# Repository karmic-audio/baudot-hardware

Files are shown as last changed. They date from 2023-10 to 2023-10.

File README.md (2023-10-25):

# baudot hardware

Based on the Monome Teletype.

Schematic/PCB diagram converted from Eagle to KiCAD.

Firmware: https://github.com/karmic-audio/baudot-software

## License

CC-BY-SA 3.0. Do not use the name "monome" or "teletype" in derivative works.

Created by brian crabtree (bcrabtree@monome.org)
Modified by Serge Bazanski (q3k@q3k.org) for Karmic Audio.

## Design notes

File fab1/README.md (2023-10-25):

Production files used for the first fabrication run of the Baudot.

Started at: March 2023

PCB Manufacturer: Aisler

PCB assembly: Karmic

Module asembly: Karmic

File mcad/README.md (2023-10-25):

Mechanicals for Baudot
===

screen-frame.FCStd
---

Screen frame used between OLED module and screen protector / front panel.

Designed with FreeCAD.

button.FCStd
---

NMI button for placement over microswitch.

Designed with FreeCAD.

screen-protector.slvs
---

Screen protector cutout from PETG.

Designed with Solvespace, because DXF/SVG export from FreeCAD confuses me.

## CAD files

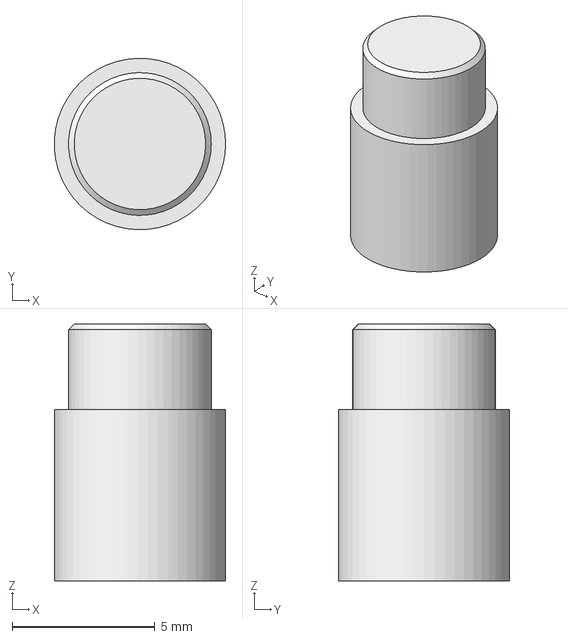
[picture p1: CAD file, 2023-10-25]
mcad/button.FCStd
5.99 x 6.00 x 9.00 mm

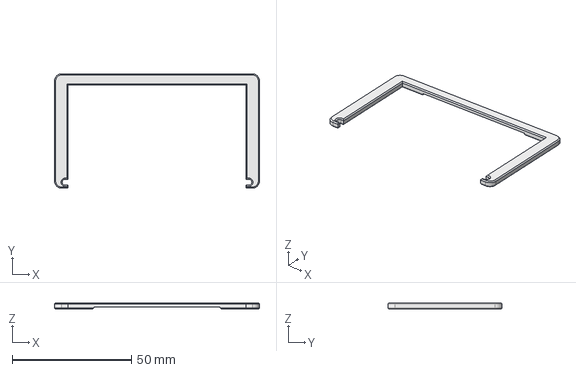
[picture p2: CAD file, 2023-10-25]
mcad/screen-frame.FCStd
86.0 x 48.0 x 2.70 mm

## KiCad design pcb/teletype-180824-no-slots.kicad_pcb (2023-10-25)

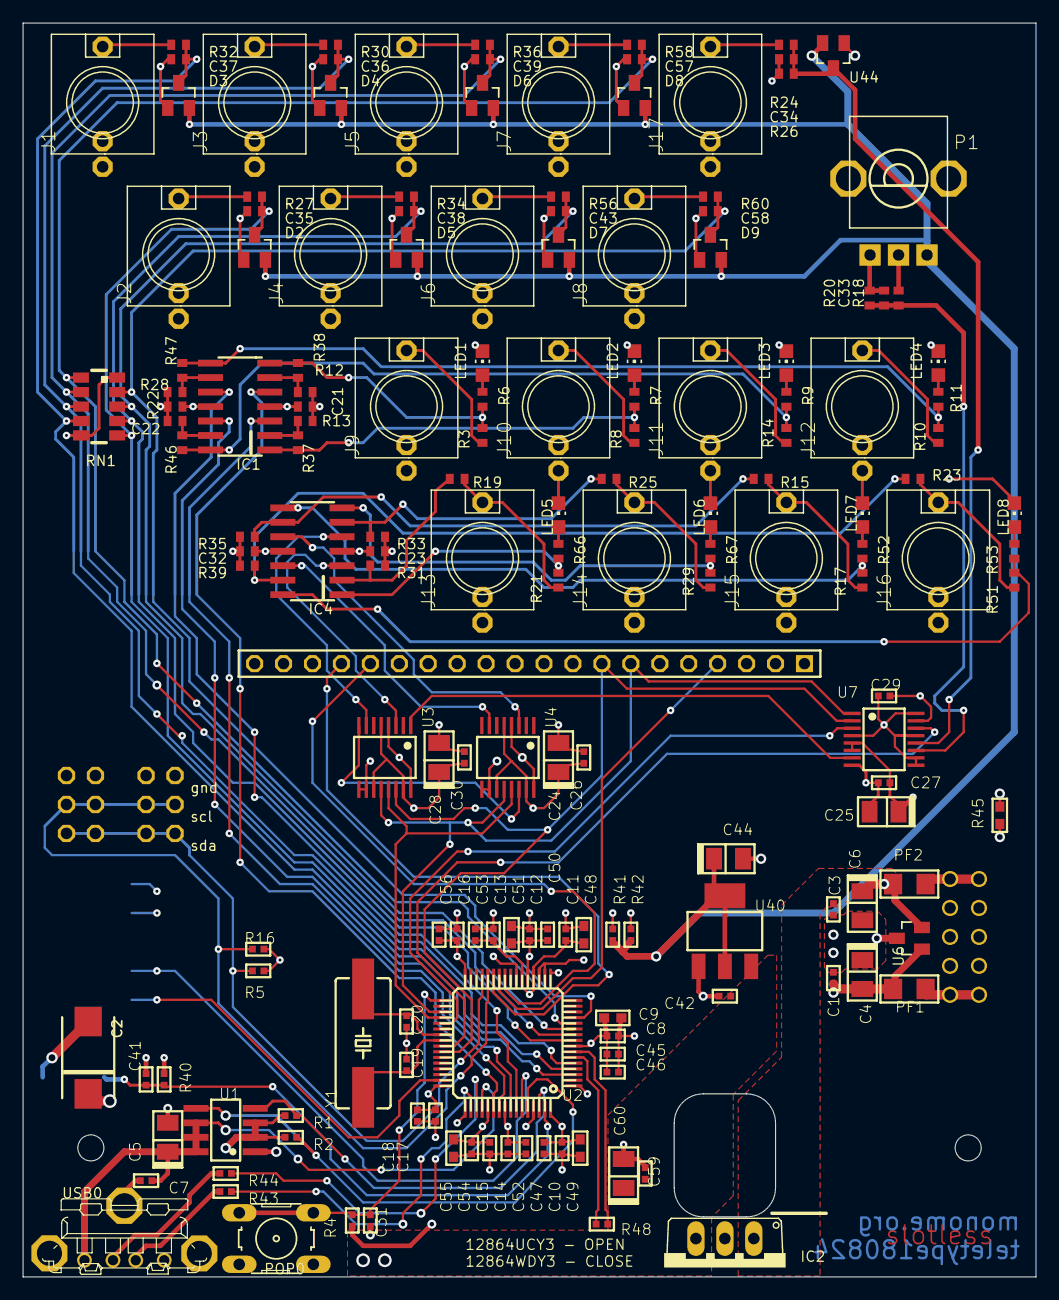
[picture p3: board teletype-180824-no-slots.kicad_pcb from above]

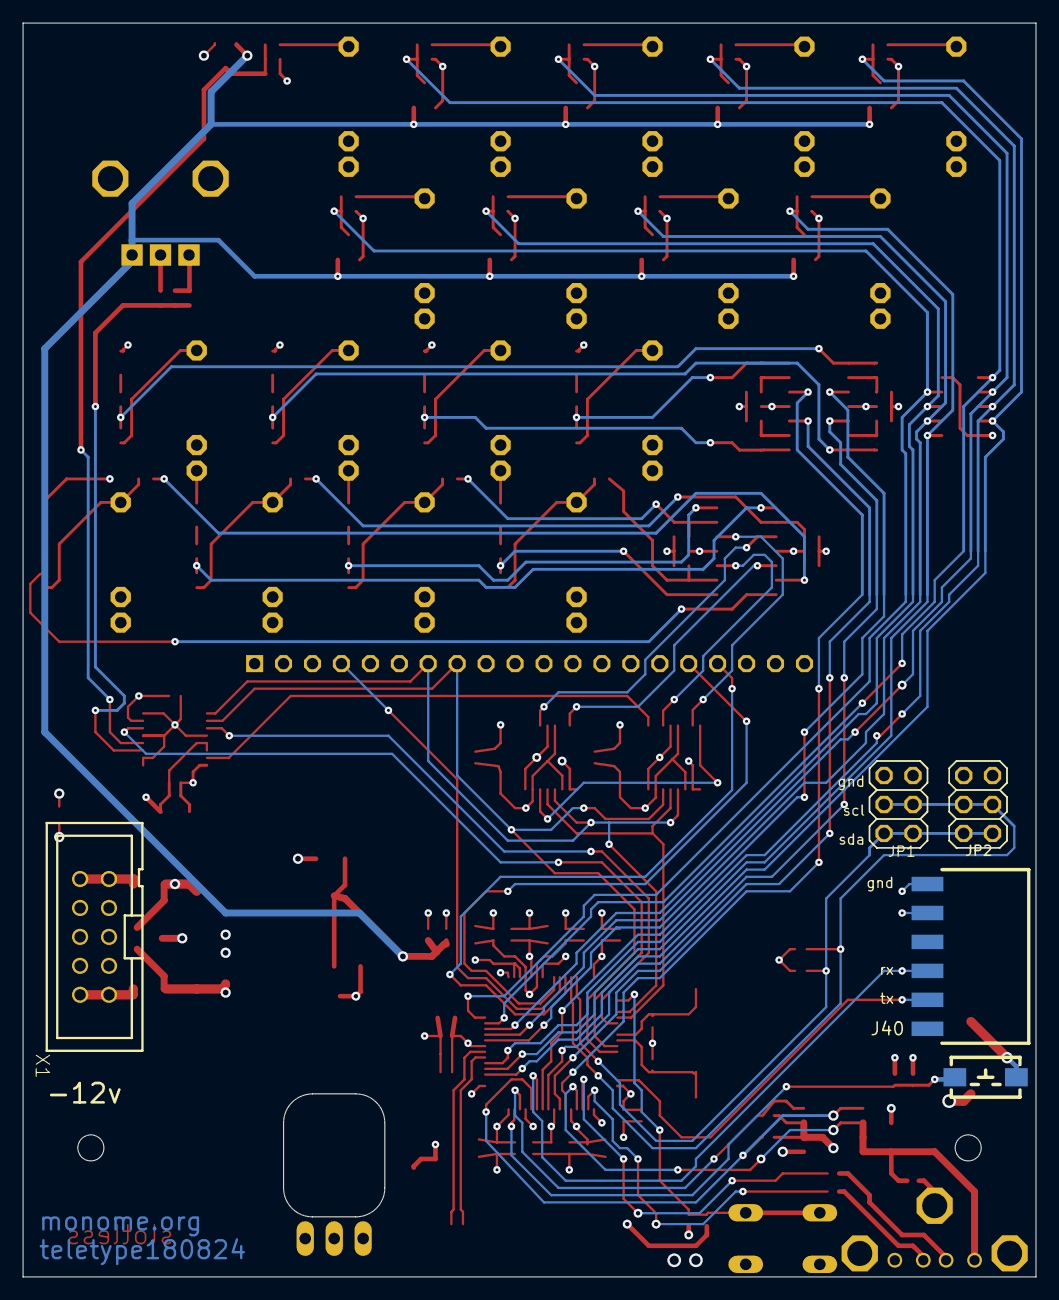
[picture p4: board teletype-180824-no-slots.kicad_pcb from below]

Board: 4 copper layers, 88.9 x 110.0 mm, 172 parts (5 on the bottom side), 98 nets.

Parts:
C1, C3, C7, C18, C21, C22, C23, C26, C27, C29, C30, C31, C32, C41, C42, C46, C47, C50, C56, C59: 100n; C0402
C2: 220u; C7343-43
C4, C6, C24, C25, C28, C44, C60: 10u; C1206_T
C5: 4.7u; C1206_T
C8, C13, C14, C15: 2.7n; C0402
C9, C48, C55: 2.2u; C0603
C10, C12, C16, C17, C33, C45, C52, C53, C54: 33n; C0402
C11: 470p; C0402
C19, C20: 22p; C0402
C34, C35, C36, C37, C38, C39, C43, C57, C58: 1n; C0402
C49, C51: 4.7u; C0603
D2, D3, D4, D5, D6, D7, D8, D9: BAS70-04; SOT23
IC1: TL074; SO14
IC2: OKI-78SR; TO220V
IC4: OPA4171; SO14
J1, J2, J3, J4, J5, J6, J7, J8, J9, J10, J11, J12, J13, J14, J15, J16, J17: WQP-PJ301M-12_JACK
J40: ISP-ROW
JP1, JP2: 2X03
JP5: OLED128X64; OLED-ALEPH
LED1, LED2, LED3, LED4: OR; CHIP-LED0805
LED5, LED6, LED7, LED8: W; CHIP-LED0805
P1: 10k; ALPS_POT_VERTICAL
PF1, PF2: PTC-F0805-15V; F1206
POP0: SWITCH-OMRON_B3F-10XX
R1, R2: 47k; R0402
R3, R8, R10, R14, R17, R21, R29, R51: 1k; R0402
R4, R6, R7, R9, R11, R12, R13, R18, R22, R26, R28, R31, R33, R35, R39, R40: 10k; R0402
R5, R16: 2k; R0402
R15, R19, R23, R24, R25, R27, R30, R32, R34, R36, R56, R58, R60: 30k; R0402
R20: 31k6; R0402
R37, R38, R46, R47, R52, R53, R66, R67: 20k; R0402
R41, R42, R48: 0; R0402
R43, R44: 39; R0402
R45: 0; R0603
RN1: 47k; MNR35
SW40: PANASONIC-EVQ
U1: TPS2021; SO08
U2: AT32UC3B064/0128/0256; TQFP64-10X10
U3, U4: AD5687R; TSSOP16
U6, U44: BAS70-04; SOT23
U7: AD7923; TSSOP16
U40: ADP3339; SOT223
USB0: SHAPES_PONY_MOLEX-USB-VERT; SHAPES_PONY_MOLEX-USB
X1: 2510-; PAK100_2500-10
Y1: 12mhz; HC49UP

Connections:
+3V3: C24.+, C25.+, C26.2, C27.2, C28.+, C29.2, C30.2, C44.+, D2.2, D3.2, D4.2, D5.2, D6.2, D7.2, D8.2, D9.2, JP5.2, P1.P$1, R4.2, R5.2, R16.2, R40.2, R41.2, R42.2, U2.18, U2.19, U3.5, U3.11, U3.15, U4.5, U4.11, U4.15, U7.5, U7.6, U7.15, U40.2, U40.4, U44.2
+5V: C2.+, C42.2, C59.2, C60.+, IC2.3, R1.2, R2.2, U1.2, U1.3, U40.3
+12V: C3.2, C6.+, C21.1, C23.1, IC1.4, IC2.1, IC4.4, PF2.2, U6.2
+IN: PF2.1, X1.9, X1.10
-12V: C1.2, C4.-, C22.2, C32.2, IC1.11, IC4.11, PF1.2, U6.1
-IN: PF1.1, X1.1, X1.2
A00: C37.1, D3.3, R32.2, RN1.7, U2.3
A01: C35.1, D2.3, R27.2, RN1.5, U2.4
A02: C36.1, D4.3, R30.2, RN1.8, U2.5
A03: C38.1, D5.3, R34.2, RN1.4, U2.9
A04: C39.1, D6.3, R36.2, RN1.9, U2.10
A05: C43.1, D7.3, R56.2, RN1.3, U2.11
A06: C57.1, D8.3, R58.2, RN1.10, U2.12
A07: C58.1, D9.3, R60.2, RN1.2, U2.13
AGND: C24.-, C25.-, C26.1, C27.1, C28.-, C29.1, C30.1, C33.2, C34.2, P1.P$3, R20.2, R26.1, R45.1, U3.4, U3.9, U3.10, U3.16, U4.4, U4.9, U4.10, U4.16, U7.4, U7.8, U7.9, U7.10, U7.13, U7.16, U44.1
B08: IC1.5, U2.54
B09: IC1.3, U2.55
B10: IC1.12, U2.57
B11: IC1.10, U2.58
CS0: U2.36, U3.13, U4.13
CS1: U2.37, U7.3
CS2: JP5.17, U2.27
CV-IN0: C34.1, R24.2, R26.2, U7.12, U44.3
CV-IN1: C33.1, R18.2, R20.1, U7.11
CV-OUT0: IC4.3, U3.3
CV-OUT1: IC4.5, U3.7
CV-OUT2: IC4.10, U4.3
CV-OUT3: IC4.12, U4.7
DM: R44.2, USB0.2
DP: R43.2, USB0.3
GND: C1.1, C2.-, C3.1, C4.+, C5.-, C6.-, C7.1, C8.1, C9.1, C10.1, C11.1, C12.1, C13.1, C14.1, C15.1, C16.1, C17.1, C18.1, C19.1, C20.1, C21.2, C22.1, C23.2, C31.2, C32.1, C35.2, C36.2, C37.2, C38.2, C39.2, C41.2, C42.1, C43.2, C44.-, C45.1, C46.1, C47.1, C48.1, C49.1, C50.1, C51.1, C52.1, C53.1, C54.1, C55.1, C56.1, C57.2, C58.2, C59.1, C60.-, D2.1, D3.1, D4.1, D5.1, D6.1, D7.1, D8.1, D9.1, IC2.2, J1.SLEEVE, J2.SLEEVE, J3.SLEEVE, J4.SLEEVE, J5.SLEEVE, J6.SLEEVE, J7.SLEEVE, J8.SLEEVE, J9.SLEEVE, J10.SLEEVE, J11.SLEEVE, J12.SLEEVE, J13.SLEEVE, J14.SLEEVE, J15.SLEEVE, J16.SLEEVE, J17.SLEEVE, J17.TS, J40.1, J40.2, JP1.5, JP1.6, JP2.5, JP2.6, JP5.1, JP5.5, JP5.6, JP5.9, JP5.10, JP5.11, JP5.12, JP5.13, JP5.14, JP5.19, JP5.20, LED1.C, LED2.C, LED3.C, LED4.C, LED5.C, LED6.C, LED7.C, LED8.C, POP0.3, POP0.4, R12.1, R13.1, R22.1, R28.1, R31.1, R33.1, R35.1, R39.1, R45.2, RN1.1, RN1.6, SW40.1, U1.1, U2.1, U2.17, U2.23, U2.49, U2.61, U6.3, U40.1, USB0.GND, USB0.M1, USB0.M2, USB0.M4, X1.3, X1.4, X1.5, X1.6, X1.7, X1.8
MISO: U2.41, U7.14
MOSI: JP5.8, U2.42, U3.14, U7.2
unnamed: R44.1, U2.51
unnamed: R43.1, U2.50
unnamed: IC1.7, R3.1, R6.1, R38.2
unnamed: U3.8, U4.14
unnamed: IC1.1, R7.1, R8.1, R37.2
unnamed: IC1.14, R9.1, R14.1, R46.2
unnamed: IC1.8, R10.1, R11.1, R47.2
unnamed: J9.TIP, R3.2
unnamed: J10.TIP, R8.2
unnamed: J11.TIP, R14.2
unnamed: J12.TIP, R10.2
unnamed: P1.P$2, R18.1
unnamed: IC4.1, R21.1, R66.1
unnamed: C20.2, U2.39, Y1.2
unnamed: IC4.7, R29.1, R67.1
unnamed: LED5.A, R66.2
unnamed: R48.1, U2.6
unnamed: R48.2, U2.7
unnamed: J15.TIP, R15.2, R17.2
unnamed: J16.TIP, R23.2, R51.2
unnamed: IC4.8, R17.1, R52.1
unnamed: LED6.A, R67.2
unnamed: IC4.14, R51.1, R53.1
unnamed: LED7.A, R52.2
unnamed: LED8.A, R53.2
unnamed: J13.TIP, R19.2, R21.2
unnamed: J17.TIP, R24.1
unnamed: J14.TIP, R25.2, R29.2
unnamed: J2.TIP, R27.1
unnamed: J3.TIP, R30.1
unnamed: J4.TIP, R34.1
unnamed: J1.TIP, R32.1
unnamed: J5.TIP, R36.1
unnamed: J6.TIP, R56.1
unnamed: J7.TIP, R58.1
unnamed: J8.TIP, R60.1
unnamed: LED1.A, R6.2
unnamed: LED2.A, R7.2
unnamed: LED3.A, R9.2
unnamed: LED4.A, R11.2
unnamed: C19.2, U2.40, Y1.1
NMI: C31.1, POP0.1, POP0.2, R4.1, U2.33
OLED-DC: JP5.4, U2.26
OLED-RES: JP5.16, U2.25
RESET: C41.1, R40.1, SW40.2, U2.63
RG1: IC1.6, R12.2, R38.1
RG2: IC1.2, R13.2, R37.1
RG3: IC1.13, R22.2, R46.1
RG4: IC1.9, R28.2, R47.1
RG5: IC4.2, R19.1, R31.2
RG6: IC4.6, R25.1, R33.2
RG7: IC4.9, R15.1, R35.2
RG8: IC4.13, R23.1, R39.2
RX: J40.4, U2.59
SCK: JP5.7, U2.35, U3.12, U4.12, U7.1
SCL: JP1.3, JP1.4, JP2.3, JP2.4, R16.1, U2.28
SDA: JP1.1, JP1.2, JP2.1, JP2.2, R5.1, U2.29
TX: J40.5, U2.47
USB-OC: R2.1, U1.5, U2.60
USB-VBOF: R1.1, U1.4, U2.62
VBUS: C5.+, C7.2, U1.6, U1.7, U1.8, U2.52, USB0.1
VDDIN: C12.2, C50.2, C51.2, R42.1, U2.21
VDDIO: C10.2, C16.2, C17.2, C18.2, C47.2, C49.2, C56.2, R41.1, U2.32, U2.48, U2.64
VDDOUT: C8.2, C9.2, C11.2, C13.2, C14.2, C15.2, C45.2, C46.2, C48.2, C52.2, C53.2, C54.2, C55.2, U2.8, U2.20, U2.22, U2.53, U2.56
VREF: U3.1, U7.7

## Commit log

2023-10-25 kicad: init from slotless
    [teletype-180824-no-slots.kicad_pcb, teletype-180824-no-slots.kicad_sch, teletype-180824-no-slots_2.kicad_sch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]
2023-10-25 mcad: init
    [button.FCStd, screen-frame.FCStd]
2023-10-25 fab1: init
    [teletype-180824-no-slots-B_Cu.gbr, teletype-180824-no-slots-B_Mask.gbr, teletype-180824-no-slots-B_Paste.gbr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]
2023-10-25 *: Cleanup leftovers from original repo
    [teletype-180824-no-slots.brd, teletype-180824-no-slots.kicad_pcb, teletype-180824-no-slots.kicad_sch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]
